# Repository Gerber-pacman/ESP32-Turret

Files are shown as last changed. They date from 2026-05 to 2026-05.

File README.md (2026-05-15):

# ESP32-Turret
Simple Stepper Motor Turret controled by esp32

{3BE2F462-789D-4FFB-A346-5BD9A529B452}

obraz
For this project I have used Esp32 in a arduino uno shape.
For stepper motors I have used 2x ATD5833.
I have included PCB files, its a pretty simple pcb that connects everything nicely.

https://www.printables.com/model/1445566-laser-pointer-robot

If I forgot to include anything please let me know.
Have fun

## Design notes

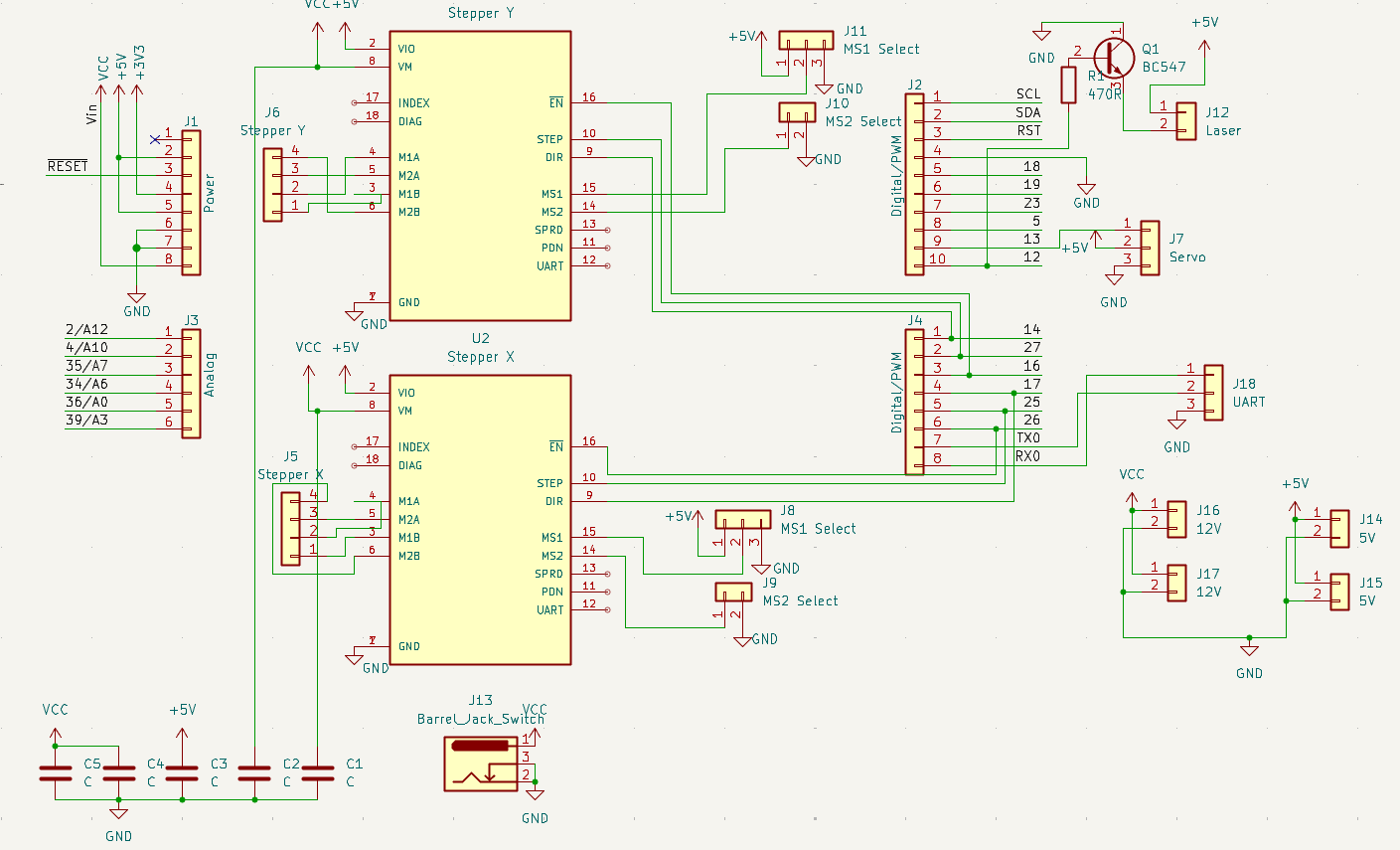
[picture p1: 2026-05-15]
PCB Files/Schematic.png

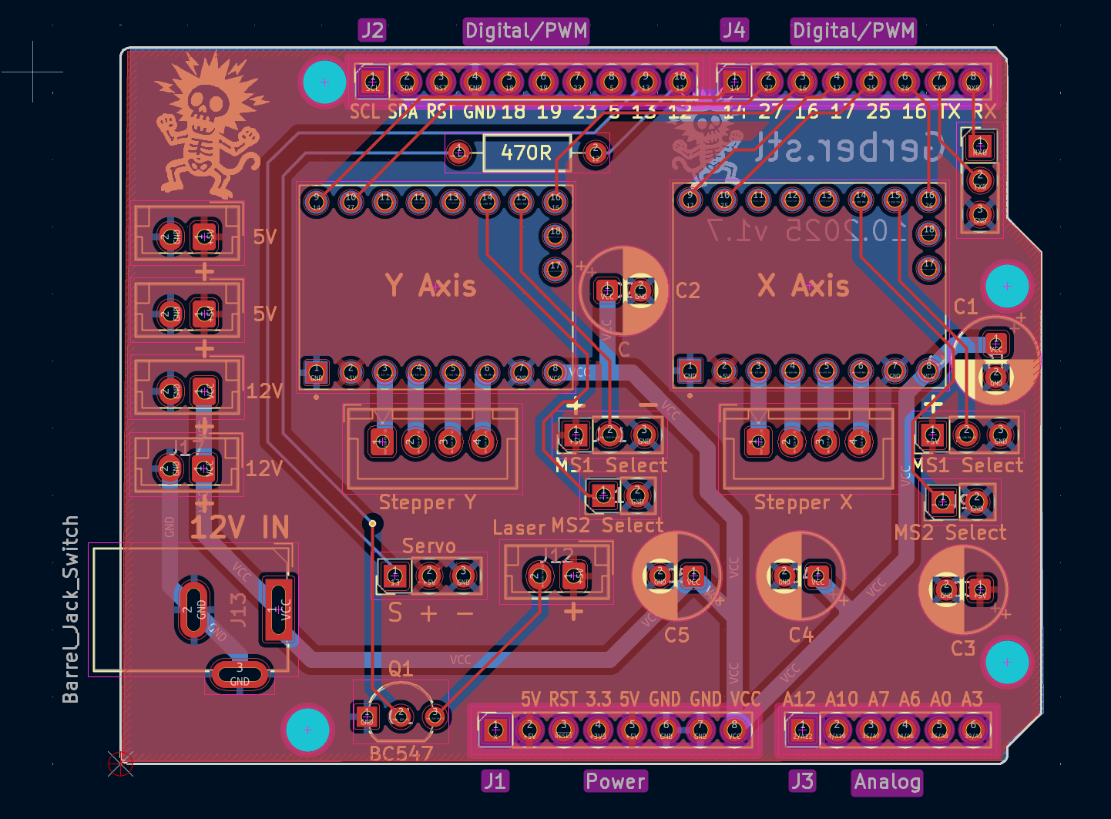
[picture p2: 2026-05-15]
PCB Files/PCB.png

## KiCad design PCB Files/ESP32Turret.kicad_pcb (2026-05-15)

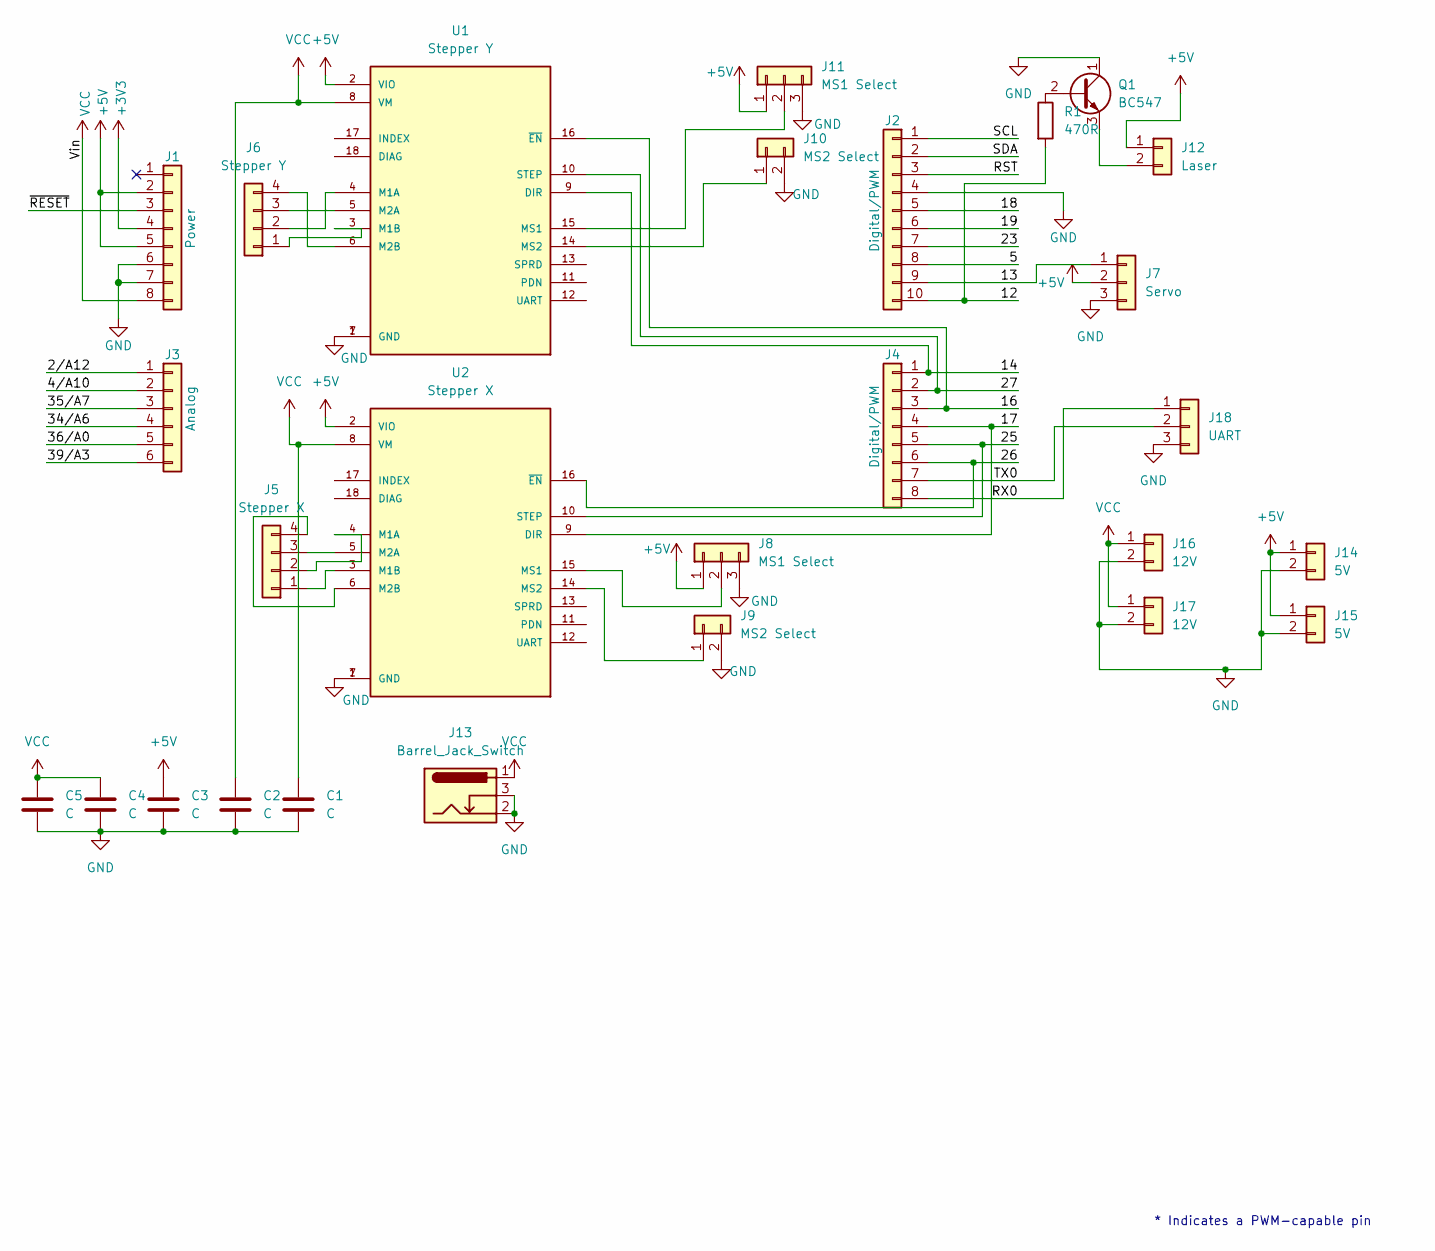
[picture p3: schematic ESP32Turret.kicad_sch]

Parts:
C1, C2, C3, C4, C5: C; CP_Radial_D6.3mm_P2.50mm
J1: Power; PinSocket_1x08_P2.54mm_Vertical
J2: Digital/PWM; PinSocket_1x10_P2.54mm_Vertical
J3: Analog; PinSocket_1x06_P2.54mm_Vertical
J4: Digital/PWM; PinSocket_1x08_P2.54mm_Vertical
J5: Stepper X; JST_XH_B4B-XH-A_1x04_P2.50mm_Vertical
J6: Stepper Y; JST_XH_B4B-XH-A_1x04_P2.50mm_Vertical
J7: Servo; PinHeader_1x03_P2.54mm_Vertical
J8, J11: MS1 Select; PinHeader_1x03_P2.54mm_Vertical
J9, J10: MS2 Select; PinHeader_1x02_P2.54mm_Vertical
J12: Laser; JST_EH_B2B-EH-A_1x02_P2.50mm_Vertical
J13: Barrel_Jack_Switch; BarrelJack_GCT_DCJ200-10-A_Horizontal
J14, J15: 5V; JST_EH_B2B-EH-A_1x02_P2.50mm_Vertical
J16, J17: 12V; JST_EH_B2B-EH-A_1x02_P2.50mm_Vertical
J18: UART; PinHeader_1x03_P2.54mm_Vertical
Q1: BC547; TO-92_Inline_Wide
R1: 470R; R_Axial_DIN0207_L6.3mm_D2.5mm_P10.16mm_Horizontal
U1: Stepper Y; MODULE_TMC2209_SILENTSTEPSTICK; PARTREV 1.20
U2: Stepper X; MODULE_TMC2209_SILENTSTEPSTICK; PARTREV 1.20

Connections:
+3V3: J1.4
+5V: C3.1, J1.2, J1.5, J7.2, J8.1, J11.1, J12.1, J14.1, J15.1, U1.2 (VIO), U2.2 (VIO)
/2/A12: J3.1
/4/A10: J3.2
/5: J2.8
/12: J2.10, R1.2
/13: J2.9, J7.1
/14: J4.1, U1.9 (DIR)
/16: J4.3, U1.16 (~EN)
/17: J4.4, U2.9 (DIR)
/18: J2.5
/19: J2.6
/23: J2.7
/25: J4.5, U2.10 (STEP)
/26: J4.6, U2.16 (~EN)
/27: J4.2, U1.10 (STEP)
/34/A6: J3.4
/35/A7: J3.3
/36/A0: J3.5
/39/A3: J3.6
/RST: J2.3
/RX0: J4.8, J18.1
/SCL: J2.1
/SDA: J2.2
/TX0: J4.7, J18.2
/~RESET: J1.3
GND: C1.2, C2.2, C3.2, C4.2, C5.2, J1.6, J1.7, J2.4, J7.3, J8.3, J9.2, J10.2, J11.3, J13.2, J13.3, J14.2, J15.2, J16.2, J17.2, J18.3, Q1.1 (C), U1.1 (GND), U1.7 (GND), U2.1 (GND), U2.7 (GND)
unnamed: J5.1, U2.3 (M1B)
unnamed: J5.2, U2.4 (M1A)
unnamed: J5.3, U2.5 (M2A)
unnamed: J5.4, U2.6 (M2B)
unnamed: J6.1, U1.3 (M1B)
unnamed: J6.2, U1.4 (M1A)
unnamed: J6.3, U1.5 (M2A)
unnamed: J6.4, U1.6 (M2B)
unnamed: J8.2, U2.15 (MS1)
unnamed: J9.1, U2.14 (MS2)
unnamed: J10.1, U1.14 (MS2)
unnamed: J11.2, U1.15 (MS1)
unnamed: J12.2, Q1.3 (E)
unnamed: Q1.2 (B), R1.1
VCC: C1.1, C2.1, C4.1, C5.1, J1.8, J13.1, J16.1, J17.1, U1.8 (VM), U2.8 (VM)

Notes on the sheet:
* Indicates a PWM-capable pin

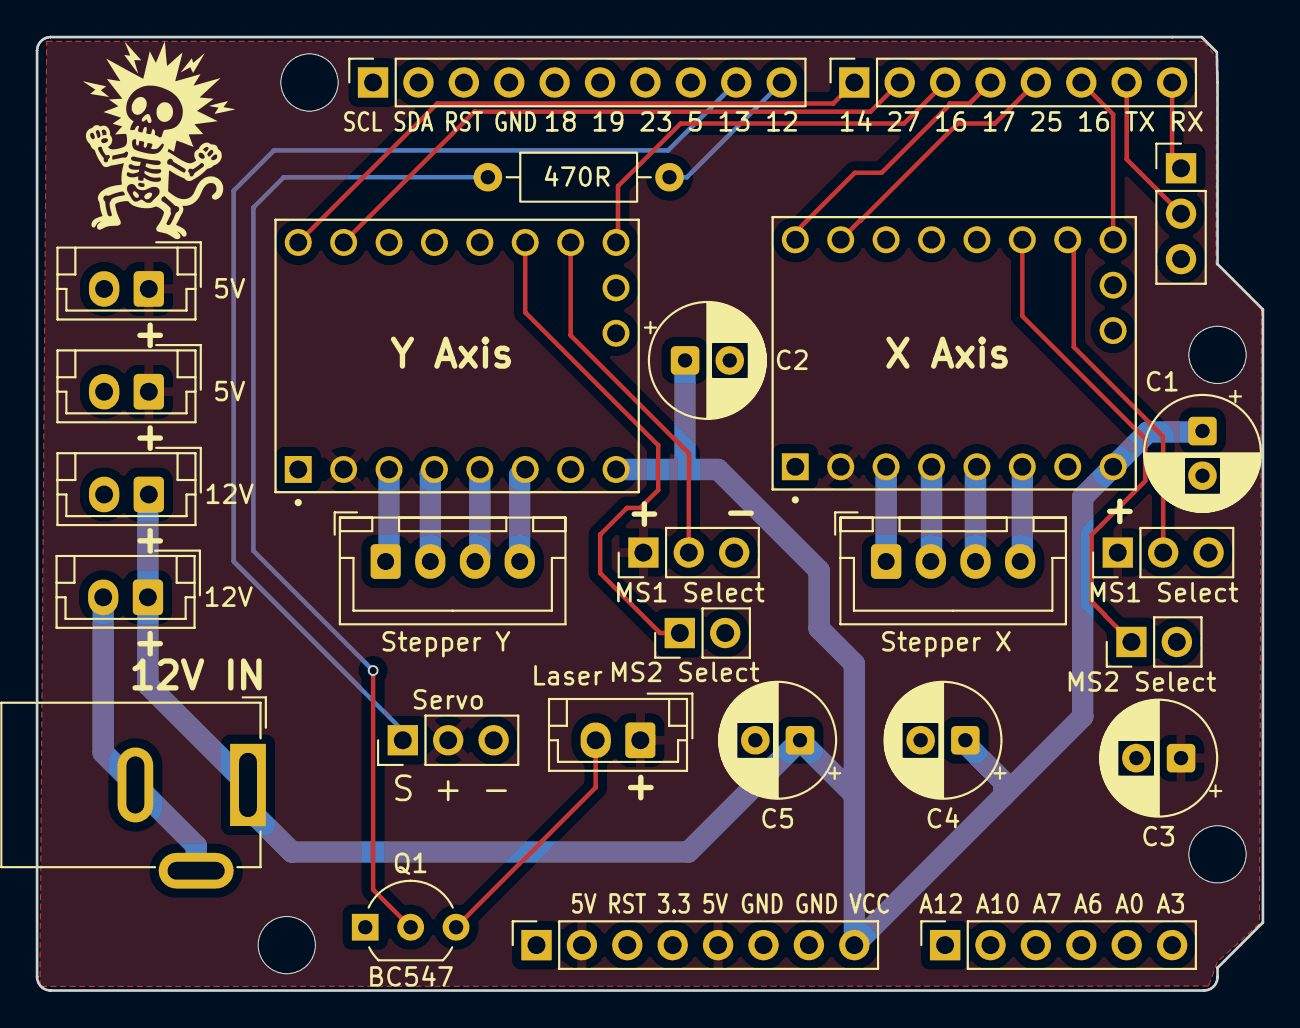
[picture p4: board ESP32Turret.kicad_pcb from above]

Board: 2 copper layers, 68.6 x 53.3 mm, 31 parts (0 on the bottom side), 27 nets.

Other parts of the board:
MH1, MH2, MH3, MH4: MountingHole_3.2mm

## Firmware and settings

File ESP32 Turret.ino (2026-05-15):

#include <AccelStepper.h>
#include <ESP32Servo.h>

// ====================================================
// KONFIGURACJA PINÓW I PARAMETRÓW
// ====================================================

// --- Serwo ---
Servo servo1;

// --- Piny silników ATD5833 ---
#define X_EN_PIN   26
#define X_STEP_PIN 25
#define X_DIR_PIN  17

#define Y_EN_PIN   16
#define Y_STEP_PIN 27
#define Y_DIR_PIN  14

// --- LED / Laser ---
#define LED_PIN 12

// --- Parametry silników ---
const int Steps_per_rev = 200 * 8;  // 1/8 mikrokrok
const int maxSpeed = 2000;
const int accel = 800;
const int deadzone = 20;

// --- Silniki ---
AccelStepper stepperX(AccelStepper::DRIVER, X_STEP_PIN, X_DIR_PIN);
AccelStepper stepperY(AccelStepper::DRIVER, Y_STEP_PIN, Y_DIR_PIN);

// --- Stany systemu ---
bool motorXEnabled = false;
bool motorYEnabled = false;
bool autoAimMode = false;  

long posX = 0;
const long posLimit = Steps_per_rev / 2;

// --- Zmienne dla klawiatury (Watchdog) ---
unsigned long lastKeyboardCmdTime = 0;
bool keyboardActive = false;

// ====================================================
// FUNKCJA: Odbiór danych z Pythona (AI oraz Klawiatura)
// ====================================================
void processSerialTracking() {
    if (Serial.available() > 0) {
        String data = Serial.readStringUntil('\n');
        data.trim(); // Usuwamy białe znaki z końca

        // ------------------------------------------------
        // 1. OBSŁUGA KLAWIATURY (K:...)
        // ------------------------------------------------
        if (data.startsWith("K:")) {
            
            // Włączanie / Wyłączanie osi X (K:TX)
            if (data.indexOf("TX") != -1) { 
                motorXEnabled = !motorXEnabled;
                digitalWrite(X_EN_PIN, motorXEnabled ? LOW : HIGH); // LOW zazwyczaj włącza sterownik
                Serial.println(motorXEnabled ? "ESP32: SILNIK X ON" : "ESP32: SILNIK X OFF");
                return;
            }
            // Włączanie / Wyłączanie osi Y (K:TY)
            else if (data.indexOf("TY") != -1) { 
                motorYEnabled = !motorYEnabled;
                digitalWrite(Y_EN_PIN, motorYEnabled ? LOW : HIGH);
                Serial.println(motorYEnabled ? "ESP32: SILNIK Y ON" : "ESP32: SILNIK Y OFF");
                return;
            }
            // Włączanie / Wyłączanie AI (K:A)
            else if (data.indexOf("A") != -1) {
                autoAimMode = !autoAimMode;
                Serial.println(autoAimMode ? "ESP32: TRYB AI ON" : "ESP32: TRYB AI OFF");
                stepperX.setSpeed(0);
                stepperY.setSpeed(0);
                return;
            }

            // Każda komenda ruchu z klawiatury wymusza wyłączenie AI dla bezpieczeństwa
            autoAimMode = false; 

            // Sterowanie jazdą ze strzałek
            if (data.indexOf("L") != -1) stepperX.setSpeed(maxSpeed / 1.5);
            else if (data.indexOf("R") != -1) stepperX.setSpeed(-maxSpeed / 1.5);
            else if (data.indexOf("U") != -1) stepperY.setSpeed(maxSpeed / 1.5);
            else if (data.indexOf("D") != -1) stepperY.setSpeed(-maxSpeed / 1.5);
            else if (data.indexOf("S") != -1) {  // Strzał (K:S)
                 servo1.write(0);
                 delay(150);
                 servo1.write(160);
                 Serial.println("ESP32: STRZAL Z SERWA");
            }
            
            // Zapisujemy czas ostatniego wciśnięcia strzałki (dla Watchdoga)
            if (data.indexOf("L") != -1 || data.indexOf("R") != -1 || data.indexOf("U") != -1 || data.indexOf("D") != -1) {
                keyboardActive = true;
                lastKeyboardCmdTime = millis(); 
            }
            return; // Kończymy, to była komenda z klawiatury
        }

        // ------------------------------------------------
        // 2. OBSŁUGA AUTO-AIM AI (X:...)
        // ------------------------------------------------
        if (data.startsWith("X:") && autoAimMode) {
            int commaIndex = data.indexOf(',');
            if (commaIndex > 0) {
                int targetX = data.substring(2, commaIndex).toInt();
                int targetY = data.substring(commaIndex + 3).toInt();

                // Błąd względem PIONOWEJ ROZDZIELCZOŚCI (240x320)
                int errorX = targetX - 120; 
                int errorY = targetY - 160;

                float autoSpeedX = 0;
                float autoSpeedY = 0;

                // Minimalna prędkość pokonująca tarcie fizyczne mechanizmu
                int minSpd = 600;  
                int maxSpd = maxSpeed / 1.5;

                // Obliczanie prędkości Oś X
                if (abs(errorX) > 15) { 
                    if (errorX > 0) autoSpeedX = map(errorX, 16, 120, -minSpd, -maxSpd); 
                    else autoSpeedX = map(errorX, -16, -120, minSpd, maxSpd);
                }
                
                // Obliczanie prędkości Oś Y
                if (abs(errorY) > 15) {
                    if (errorY > 0) autoSpeedY = map(errorY, 16, 160, -minSpd, -maxSpd);
                    else autoSpeedY = map(errorY, -16, -160, minSpd, maxSpd);
                }

                // Aplikowanie prędkości (tylko jeśli silniki są fizycznie włączone)
                if (motorXEnabled) {
                    if ((autoSpeedX > 0 && posX < posLimit) || (autoSpeedX < 0 && posX > -posLimit)) {
                        stepperX.setSpeed(autoSpeedX);
                        posX += (autoSpeedX > 0) ? 1 : -1;
                    } else {
                        stepperX.setSpeed(0);
                    }
                }
                if (motorYEnabled) {
                    stepperY.setSpeed(autoSpeedY);
                }
            }
        }
    }
}

// ====================================================
// SETUP / LOOP
// ====================================================
void setup() {
    Serial.begin(115200);
    Serial.setTimeout(10); 

    pinMode(X_EN_PIN, OUTPUT);
    pinMode(Y_EN_PIN, OUTPUT);
    pinMode(LED_PIN, OUTPUT);

    digitalWrite(X_EN_PIN, HIGH); // Domyślnie wyłączone zasilanie silników po starcie
    digitalWrite(Y_EN_PIN, HIGH);
    digitalWrite(LED_PIN, LOW);

    stepperX.setMaxSpeed(maxSpeed);
    stepperX.setAcceleration(accel);
    stepperY.setMaxSpeed(maxSpeed);
    stepperY.setAcceleration(accel);

    servo1.attach(13);
    servo1.write(160); 

    Serial.println("ESP32: SYSTEM GOTOWY. STEROWANIE TYLKO PRZEZ USB/AI.");
}

void loop() {
    // 1. Odczyt komend z USB (Klawiatura i AI z Pythona)
    processSerialTracking();

    // 2. WATCHDOG KLAWIATURY (Bezpiecznik)
    // Jeśli włączyliśmy jazdę z klawiatury, ale od 150ms nie przyszła 
    // żadna nowa litera (bo puściliśmy klawisz), to zatrzymaj robota.
    if (keyboardActive && (millis() - lastKeyboardCmdTime > 150)) {
        stepperX.setSpeed(0);
        stepperY.setSpeed(0);
        keyboardActive = false;
    }

    // 3. Bezwarunkowe odświeżanie kroków silników (Kluczowe dla AccelStepper!)
    stepperX.runSpeed();
    stepperY.runSpeed();
}

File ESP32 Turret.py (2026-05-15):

"""
Code version: 8.0
TURRET CONTROL – Python (Windows)
==================================
Requirements: pip install opencv-python pyserial pynput numpy

KEYS (work globally – camera window does not need to be focused):
  Arrow LEFT / RIGHT  → X axis  (hold = move, release = stop)
  Arrow UP   / DOWN   → Y axis  (hold = move, release = stop)
  X  – toggle X motor on/off
  Y  – toggle Y motor on/off
  A  – switch MANUAL / AUTO-AIM mode
  S  – servo toggle (0° / 160°)
  L  – laser toggle
  Q  – quit
"""

import cv2
import numpy as np
import serial
import time
import threading
from pynput import keyboard

# ============================================================
#  CONFIGURATION  ← edit these values
# ============================================================
PORT_COM  = 'COM8'   # e.g. 'COM3', 'COM7' – check Device Manager
BAUD_RATE = 115200
CAMERA_ID = 0        # 0 = built-in webcam, 1 = external USB camera

CAM_W, CAM_H = 1024, 600   # WSVGA – camera resolution before rotation

# After 90° rotation the frame becomes 600×1024 (w×h).
# We crop the center 600×600 px – no scaling.
CROP    = 600
CENTER_X = CROP // 2   # 300
CENTER_Y = CROP // 2   # 300

# HSV range for blue / navy blue
# Hue 100–130: navy (100-110), blue (110-125), royal blue (125-130)
# Low saturation floor (60) catches dark/faded navy shades
HSV_LOWER = np.array([100,  60,  30])
HSV_UPPER = np.array([130, 255, 255])
MIN_CONTOUR_AREA = 2000   # ignore noise smaller than this (px²)

# ============================================================
#  ESP32 CONNECTION
# ============================================================
try:
    esp32 = serial.Serial(PORT_COM, BAUD_RATE, timeout=0.1)
    time.sleep(2)
    print(f"[OK] Connected to ESP32 on {PORT_COM}")
except Exception as e:
    esp32 = None
    print(f"[WARNING] Could not connect to ESP32: {e}")
    print("          Running in camera-preview-only mode.")

_serial_lock = threading.Lock()

def send(cmd: str):
    """Send a newline-terminated command to the ESP32."""
    if esp32:
        with _serial_lock:
            try:
                esp32.write((cmd + '\n').encode())
            except Exception as ex:
                print(f"[SERIAL ERROR] {ex}")

# ============================================================
#  APPLICATION STATE  (shared between threads)
# ============================================================
auto_aim = False   # True = auto-tracking mode
running  = True    # False = shut down
servo_held = False # True = S is currently physically held down

# Set of currently held movement directions
held_dirs = set()
held_lock = threading.Lock()

# Last sent movement commands – avoid flooding the ESP32 with duplicates
prev_cmd_x = None
prev_cmd_y = None

# ============================================================
#  KEYBOARD HANDLER  (pynput – runs in a background thread)
# ============================================================
TOGGLE_KEYS = {
    keyboard.KeyCode.from_char('x'): 'CMD:MOTOR_X',
    keyboard.KeyCode.from_char('X'): 'CMD:MOTOR_X',
    keyboard.KeyCode.from_char('y'): 'CMD:MOTOR_Y',
    keyboard.KeyCode.from_char('Y'): 'CMD:MOTOR_Y',
    keyboard.KeyCode.from_char('a'): 'CMD:MODE',
    keyboard.KeyCode.from_char('A'): 'CMD:MODE',
    # S handled separately as press/release – not in TOGGLE_KEYS
    keyboard.KeyCode.from_char('l'): 'CMD:LASER',
    keyboard.KeyCode.from_char('L'): 'CMD:LASER',
}

ARROW_KEYS = {
    keyboard.Key.left:  'LEFT',
    keyboard.Key.right: 'RIGHT',
    keyboard.Key.up:    'UP',
    keyboard.Key.down:  'DOWN',
}

def on_press(key):
    global auto_aim, running

    # Quit
    if key in (keyboard.KeyCode.from_char('q'), keyboard.KeyCode.from_char('Q')):
        running = False
        return False   # stops the listener

    # Servo – press = move to 0°, release = return to 160°
    # servo_held blocks autorepeat from firing multiple toggles.
    if key in (keyboard.KeyCode.from_char('s'), keyboard.KeyCode.from_char('S')):
        global servo_held
        if not servo_held:
            servo_held = True
            send('CMD:SERVO')
        return

    # One-shot toggle commands
    if key in TOGGLE_KEYS:
        cmd = TOGGLE_KEYS[key]
        send(cmd)
        if 'MODE' in cmd:
            auto_aim = not auto_aim
            print(f"[MODE] {'AUTO-AIM' if auto_aim else 'MANUAL'}")
        return

    # Arrow keys – add direction to held set (manual mode only)
    if key in ARROW_KEYS and not auto_aim:
        with held_lock:
            held_dirs.add(ARROW_KEYS[key])

def on_release(key):
    global servo_held
    # Servo release – send toggle again to return to 160°
    if key in (keyboard.KeyCode.from_char('s'), keyboard.KeyCode.from_char('S')):
        servo_held = False
        send('CMD:SERVO')
        return
    # Always remove direction on key release, regardless of mode
    if key in ARROW_KEYS:
        with held_lock:
            held_dirs.discard(ARROW_KEYS[key])

listener = keyboard.Listener(on_press=on_press, on_release=on_release)
listener.daemon = True
listener.start()

# ============================================================
#  CAMERA
# ============================================================
cap = cv2.VideoCapture(CAMERA_ID)
cap.set(cv2.CAP_PROP_FRAME_WIDTH,  CAM_W)
cap.set(cv2.CAP_PROP_FRAME_HEIGHT, CAM_H)

if not cap.isOpened():
    print("[ERROR] Cannot open camera!")
    if esp32:
        esp32.close()
    exit(1)

# ============================================================
#  ON-SCREEN DISPLAY
# ============================================================
def draw_osd(frame, mode_auto, target=None):
    h, w = frame.shape[:2]

    # Mode label (bottom-left)
    col   = (0, 200, 0) if mode_auto else (0, 180, 255)
    label = "MODE: AUTO-AIM" if mode_auto else "MODE: MANUAL"
    cv2.putText(frame, label, (10, h - 15),
                cv2.FONT_HERSHEY_SIMPLEX, 0.55, col, 2)

    # Crosshair at frame center
    cx, cy = CENTER_X, CENTER_Y
    cv2.line(frame,  (cx - 22, cy), (cx + 22, cy), (255, 255, 255), 2)
    cv2.line(frame,  (cx, cy - 22), (cx, cy + 22), (255, 255, 255), 2)
    cv2.circle(frame, (cx, cy), 4,  (255, 255, 255), -1)

    # Target overlay
    if target:
        tx, ty, tw, th = target
        sx, sy = tx + tw // 2, ty + th // 2
        cv2.rectangle(frame, (tx, ty), (tx + tw, ty + th), (255, 255, 0), 2)
        cv2.circle(frame, (sx, sy), 6, (0, 0, 255), -1)
        cv2.line(frame, (cx, cy), (sx, sy), (0, 255, 255), 2)
        ex, ey = sx - cx, sy - cy
        cv2.putText(frame, f"Err X:{ex:+d}  Y:{ey:+d}", (10, 30),
                    cv2.FONT_HERSHEY_SIMPLEX, 0.5, (0, 255, 255), 2)

    # Key legend (top-right)
    legend = ["X/Y - motors", "A - auto/manual", "S - servo",
              "L - laser", "Arrows - move"]
    for i, ln in enumerate(legend):
        cv2.putText(frame, ln, (w - 145, 18 + i * 18),
                    cv2.FONT_HERSHEY_SIMPLEX, 0.37, (200, 200, 200), 1)
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
